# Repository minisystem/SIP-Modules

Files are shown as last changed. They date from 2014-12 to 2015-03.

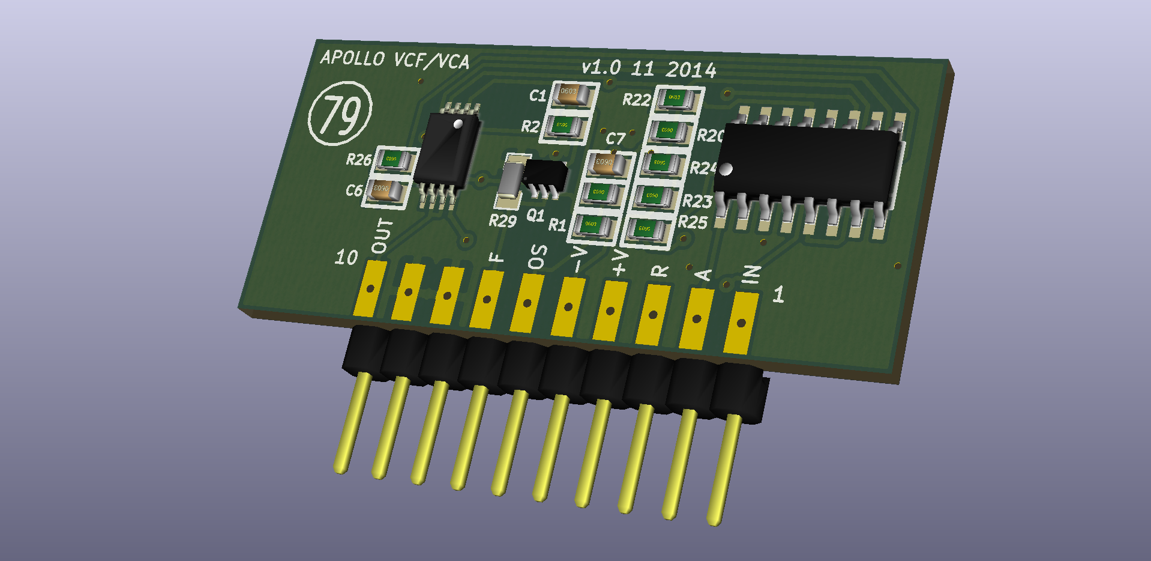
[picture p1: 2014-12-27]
VCF-VCA-SIP - Routing/VCF-VCA-SIP-back.png

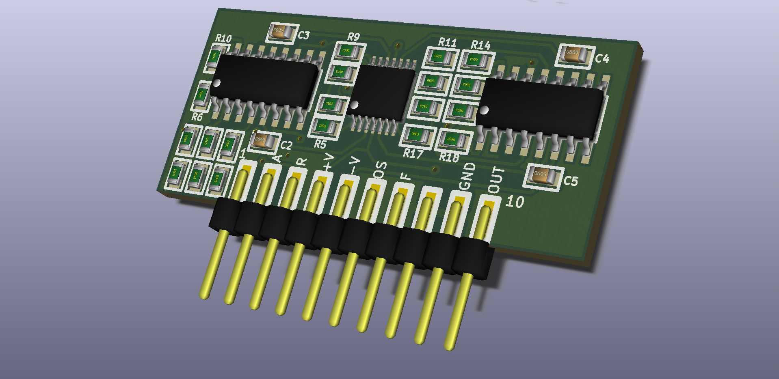
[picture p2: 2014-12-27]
VCF-VCA-SIP - Routing/VCF-VCA-SIP.png

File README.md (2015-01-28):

SIP-Modules
===========

Analogue SIP modules

Single Inline Pin [SIP] Package Modules for Analogue Synthesizer Design
===============================================================

******************************
IMPORTANT!- READ THIS FIRST!!!
*************************************************************************************************************
THESE REPOSITORIES ARE A MESS RIGHT NOW BECAUSE OF MY PREVIOUS AD HOC VERSION CONTROL
I will eventually tidy them up but at the moment I don't know which are the latest and fully correct versions 
*************************************************************************************************************

What are these?
===============

These are designs for modules that make up the bulidng blocks of an analogue synthesizer. They were inspired 
by the original Curtis Electromusic (CEM) chips used in dozens of 70s and 80s synthesizer designs. They are *NOT* 
electronically equivalent to the original CEM chips. They were designed to be compact modules for building 
a polyphonic analogue synthesizer. They use SMT parts but are designed for hand soldering. As there are parts on both sides of the board a substantial redesign might be required for automated assmebly by a pick-and-place assembly service.

VCO SIP
=======
This is an analogue Voltage Controlled Oscillator (VCO) module in a 30 mm x 18 mm 12 pin SIP package.
It is a classic SAW core design derived from the Terry Michaels/Mikulik/Electronotes/ASM-1 circuit. It employs 
waveshapers from George Hearn's HMVCO1c design, with modifications to limit output levels to 10V pp. Other
changes from the original Electronotes design include elimination of the linear FM input and swapping the CA3140 
integrator for the cheaper LF351. It uses an inexpensive BCM847 NPN matched transistor pair in contrast
to the super matched pairs (LS318, LM394, SSM2210, etc) called for in other SAW core designs.

VCF-VCA SIP
===========
This is a 4 pole LM13700 OTA-based Voltage Controlled Filter (VCF) in a 40 mm x 18 mm 10 pin SIP package.  It is derived from Roland filter designs based around the IR3109 quad OTA filter. Voltage controlled resonance is implemented with an LM13700 OTA cell and the spare OTA is used for a Voltage Controlled Amplifier (VCA), thus combining two functions into one module, similiar to the Roland D80017A VCF-VCA module used in the Juno 106.

EG ADSR SIP
===========
This is a voltage controlled Envelope Generator (EG) with Attack, Decay, Sustain and Release stages in a 30 mm x 18 mm 10 pin SIP package. It is derived from similar designs by Massimo Ischia and Scott Rider (OldCrow) with modifications to respond to 0-10V control voltages and to produce a 0-10V output.

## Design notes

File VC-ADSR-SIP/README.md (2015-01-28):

Voltage Controlled ADSR Envelope Generator
==========================================

This is a voltage controlled Envelope Generator (EG) with Attack, Decay, Sustain and Release stages in a 30 mm x 18 mm 12 pin SIP package. It is derived from similar designs by Massimo Ischia and Scott Rider (OldCrow) with modifications to respond to 0-10V control voltages and to produce a 0-10V output.

Massimo Ischia's version:
http://digilander.libero.it/ismsynth/vc-adsr-1.2.jpg

Scott Rider's version:
http://www.muffwiggler.com/forum/viewtopic.php?p=1151245
(scroll down for schematic in thread)

Notes
=====

Ideally, I'd like to eliminate the trimmers for Attack and Decay/Release times. I tried doing this in an early revision but needed to tweak the resistor values more than I expected so reverted to trimmers. However, in subsequent revisions I've hardly needed to make any adjustments at all. A 0603 or 0805 resistor should be able to bridge the T1 and T2 footprints.

Q1's schematic symbol has a pin numbering that swapped the emitter (pin 1) and base (pin 2) when used with the default SOT23 footprint. I fixed this by swapping the pad numbers on the SOT23 footprint module, but this change applies to *this project only*.

This project was created in Kicad 4022 but routed in 5112 using the CERN push and shove router. This means that the CvPcb footprint association uses the legacy library format and not the new library table format. I haven't tried to do the conversion yet.

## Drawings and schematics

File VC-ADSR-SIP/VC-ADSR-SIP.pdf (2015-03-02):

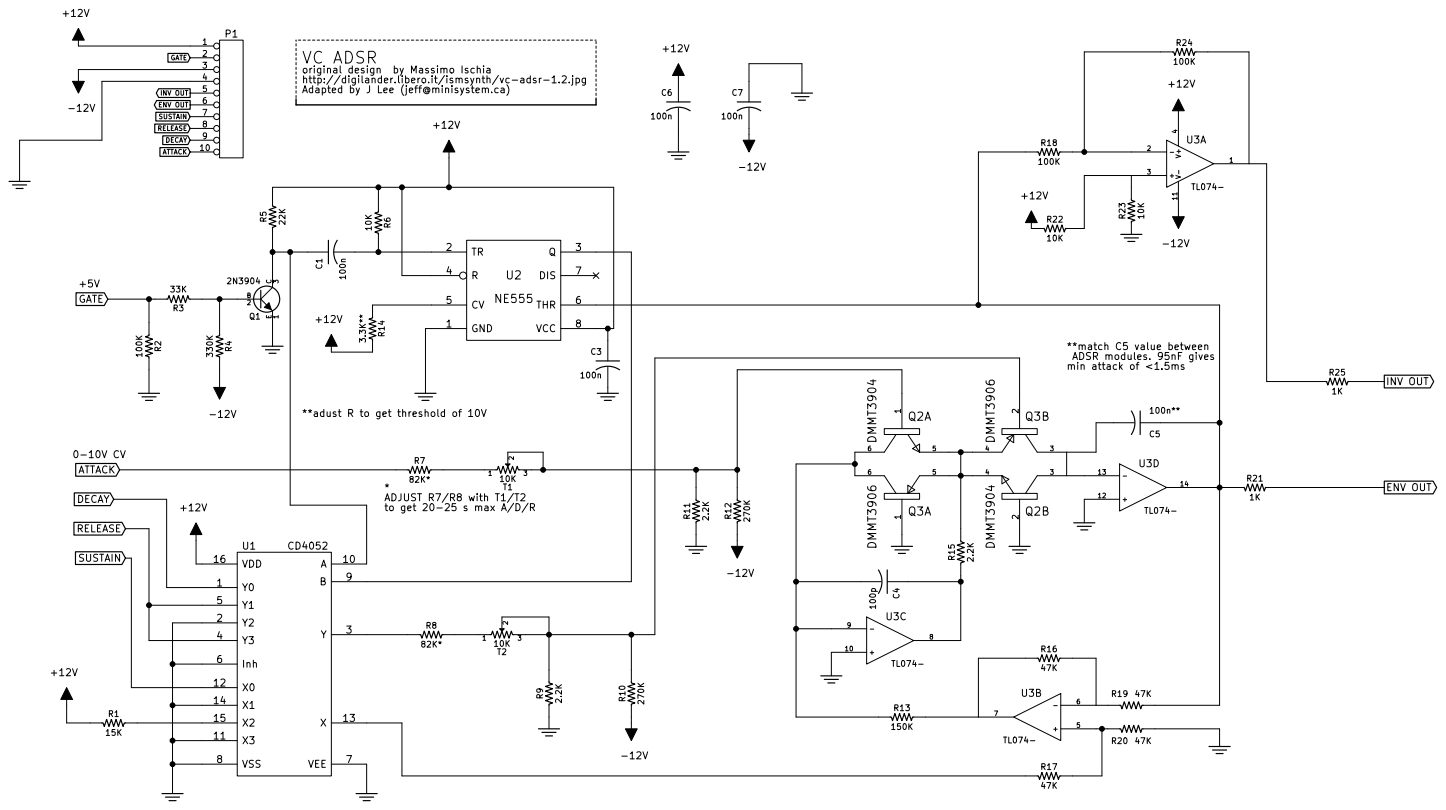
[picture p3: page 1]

original design by Massimo Ischia
http://digilander.libero.it/ismsynth/vc-adsr-1.2.jpg

ADSR modules. 95nF gives min attack of <1.5ms 0-10V CV

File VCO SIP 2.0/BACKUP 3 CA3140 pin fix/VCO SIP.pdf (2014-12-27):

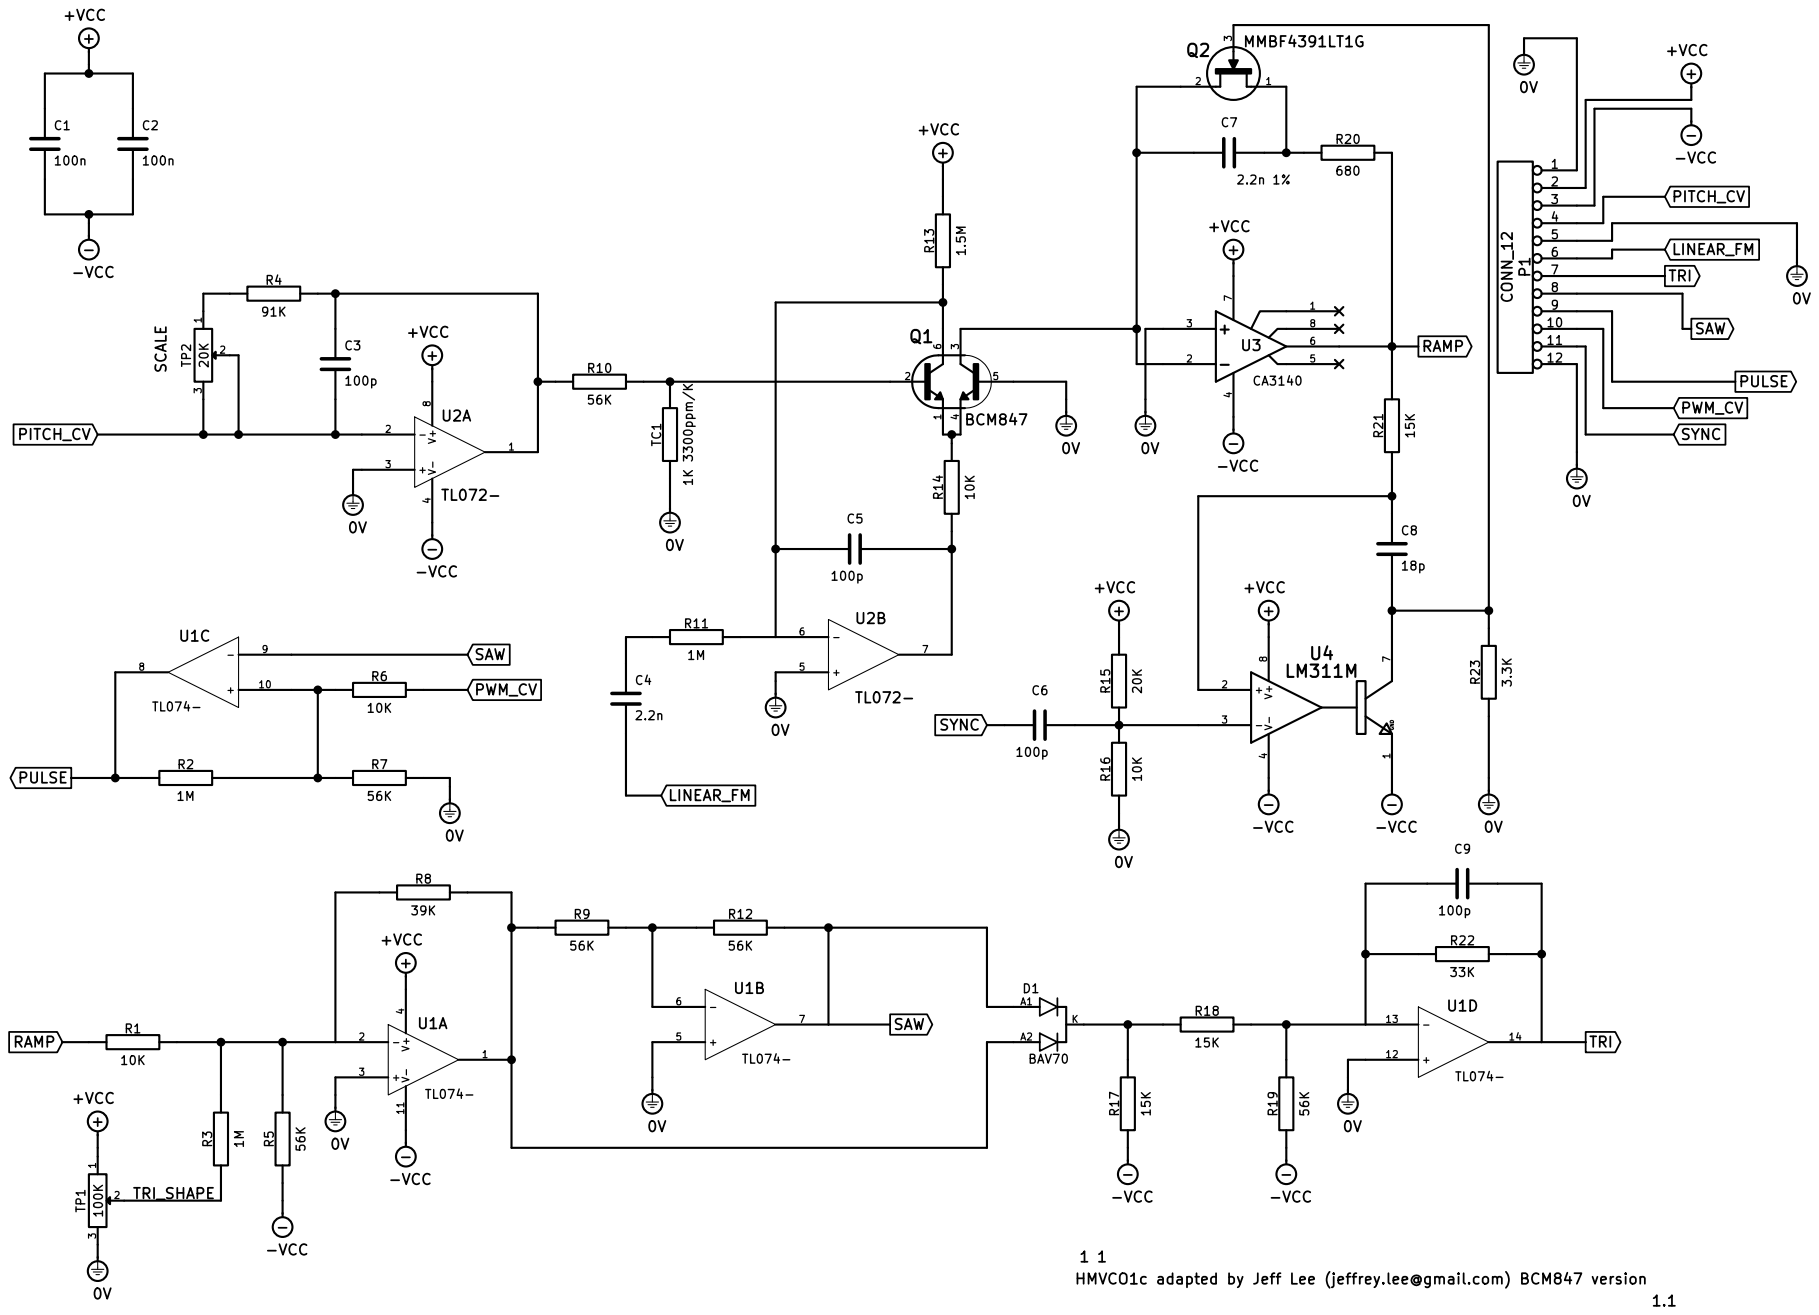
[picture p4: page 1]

1.1 HMVCO1c adapted by Jeff Lee (jeffrey.lee@gmail.com) BCM847 version

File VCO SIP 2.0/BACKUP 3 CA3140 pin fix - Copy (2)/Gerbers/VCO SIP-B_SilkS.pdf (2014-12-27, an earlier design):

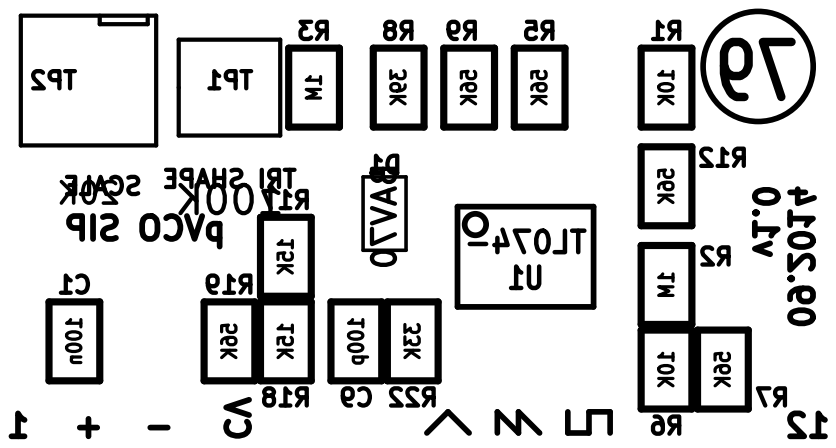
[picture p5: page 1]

SCALE TRI SHAPE 09.2014 pVCO SIP 79 BAV70 D1 TP2 20K

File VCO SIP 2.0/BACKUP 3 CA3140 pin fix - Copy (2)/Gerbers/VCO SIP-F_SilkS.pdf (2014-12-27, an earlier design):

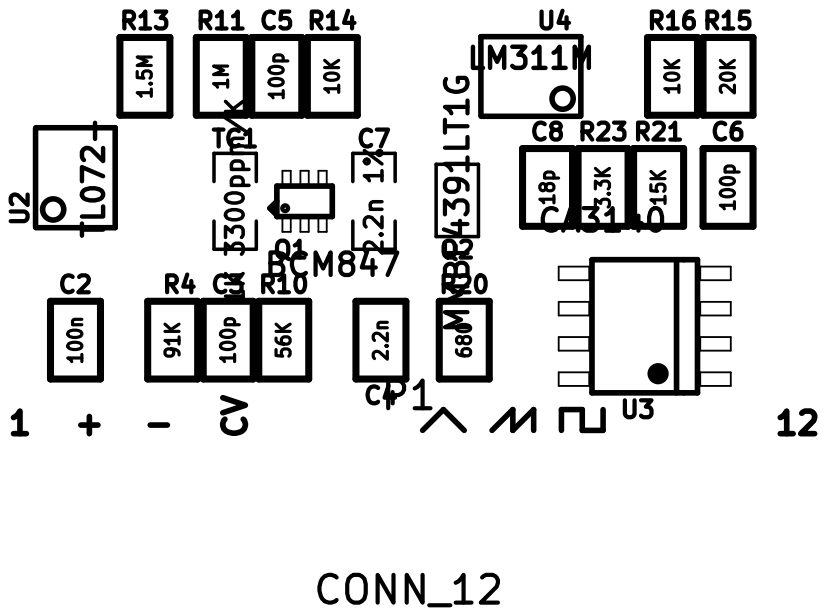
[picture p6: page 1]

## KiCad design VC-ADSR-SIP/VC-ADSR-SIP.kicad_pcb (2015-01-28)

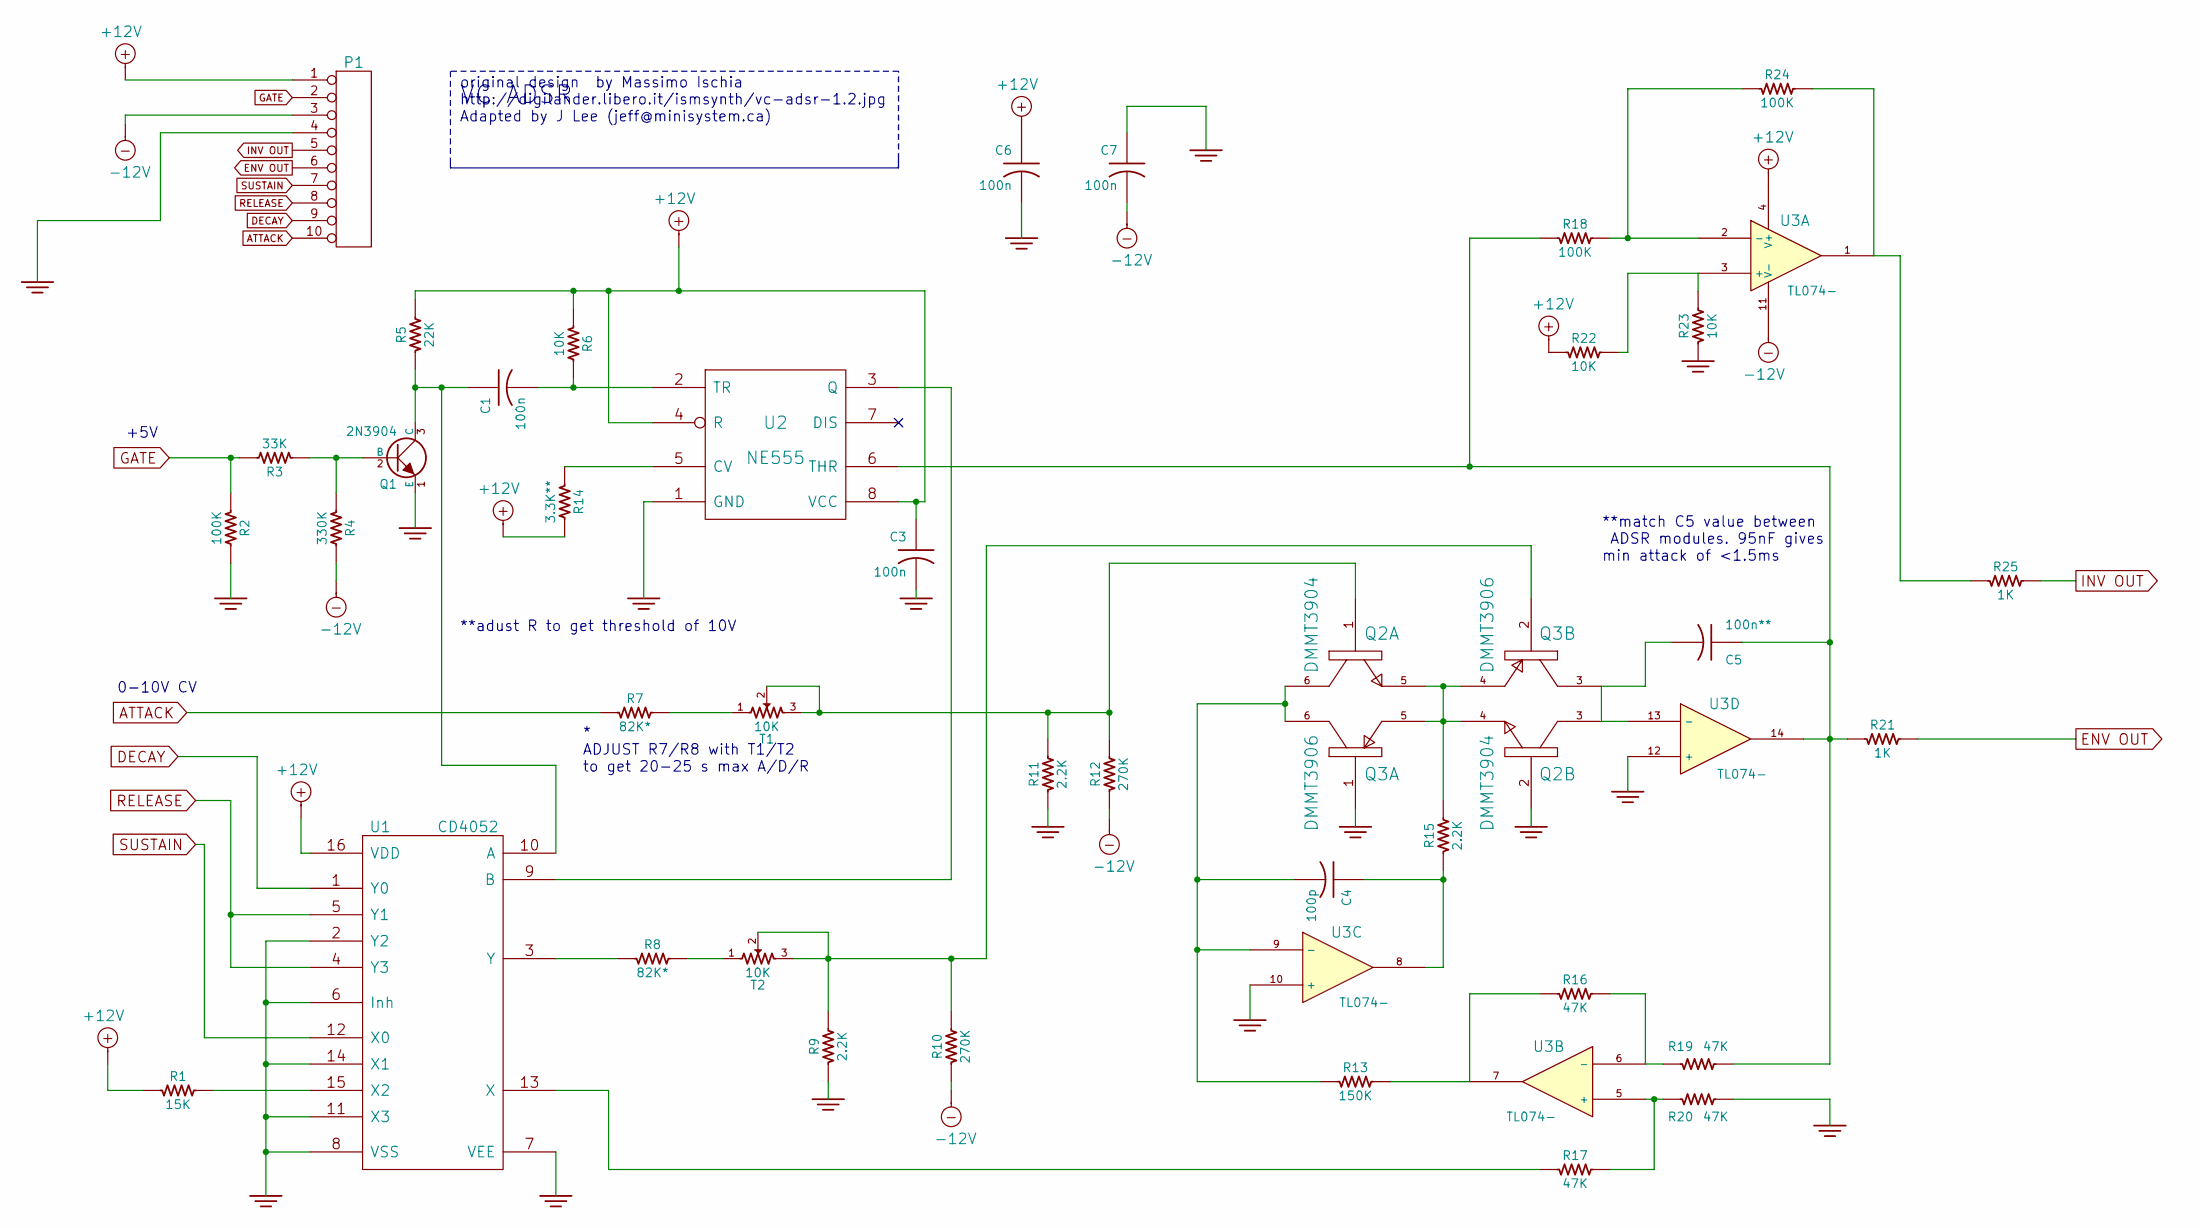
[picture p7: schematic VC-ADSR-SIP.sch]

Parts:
C1, C3, C6, C7: 100n
C4: 100p
C5: 100n**
P1: CONN_10
Q1: 2N3904
Q2: DMMT3904
Q3: DMMT3906
R1: 15K
R2, R18, R24: 100K
R3: 33K
R4: 330K
R5: 22K
R6, R22, R23: 10K
R7, R8: 82K*
R9, R11, R15: 2.2K
R10, R12: 270K
R13: 150K
R14: 3.3K**
R16, R17, R19, R20: 47K
R21, R25: 1K
T1, T2: 10K
U1: CD4052
U2: NE555
U3: TL074-

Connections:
+12V: C3.1, C6.1, P1.1, R1.1, R5.2, R6.1, R14.2, R22.1, U1.16 (VDD), U2.4 (R), U2.8 (VCC), U3.4 (V+)
-12V: C7.2, P1.3, R4.2, R10.1, R12.1, U3.11 (V-)
ATTACK: P1.10, R7.1
DECAY: P1.9, U1.1 (Y0)
ENV OUT: P1.6, R21.2
GATE: P1.2, R2.1, R3.2
GND: C3.2, C6.2, C7.1, P1.4, Q1.1 (E), Q2.2, Q3.1, R2.2, R9.1, R11.1, R20.2, R23.1, U1.2 (Y2), U1.6 (Inh), U1.7 (VEE), U1.8 (VSS), U1.11 (X3), U1.14 (X1), U2.1 (GND), U3.10 (+), U3.12 (+)
INV OUT: P1.5, R25.2
unnamed: Q1.2 (B), R3.1, R4.1
unnamed: C5.1, R18.1, R19.2, R21.1, U2.6 (THR), U3.14
unnamed: U1.9 (B), U2.3 (Q)
unnamed: C1.1, Q1.3 (C), R5.1, U1.10 (A)
unnamed: R14.1, U2.5 (CV)
unnamed: C1.2, R6.2, U2.2 (TR)
unnamed: R1.2, U1.15 (X2)
unnamed: R22.2, R23.2, U3.3 (+)
unnamed: R17.2, R20.1, U3.5 (+)
unnamed: C4.1, R15.1, U3.8
unnamed: R13.2, R16.1, U3.7
unnamed: R17.1, U1.13 (X)
unnamed: R16.2, R19.1, U3.6 (-)
unnamed: R18.2, R24.1, U3.2 (-)
unnamed: R8.2, T2.1
unnamed: R7.2, T1.1
unnamed: R24.2, R25.1, U3.1
unnamed: C5.2, Q2.3, Q3.3, U3.13 (-)
unnamed: Q2.4, Q2.5, Q3.4, Q3.5, R15.2
unnamed: R8.1, U1.3 (Y)
unnamed: Q3.2, R9.2, R10.2, T2.2, T2.3
unnamed: Q2.1, R11.2, R12.2, T1.2, T1.3
unnamed: C4.2, Q2.6, Q3.6, R13.1, U3.9 (-)
RELEASE: P1.8, U1.4 (Y3), U1.5 (Y1)
SUSTAIN: P1.7, U1.12 (X0)

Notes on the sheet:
**adust R to get threshold of 10V
* ADJUST R7/R8 with T1/T2 to get 20-25 s max A/D/R
**match C5 value between ADSR modules. 95nF gives min attack of <1.5ms
0-10V CV
+5V
VC ADSR
original design by Massimo Ischia http://digilander.libero.it/ismsynth/vc-adsr-1.2.jpg Adapted by J Lee (jeff@minisystem.ca)

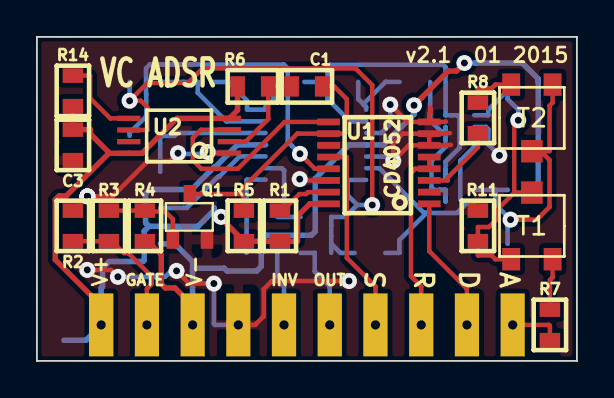
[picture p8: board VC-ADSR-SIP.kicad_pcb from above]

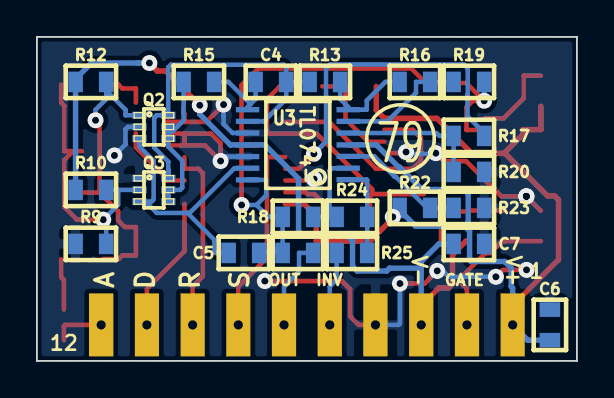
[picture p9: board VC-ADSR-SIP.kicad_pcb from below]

Board: 2 copper layers, 30.0 x 18.0 mm, 40 parts (22 on the bottom side), 33 nets.

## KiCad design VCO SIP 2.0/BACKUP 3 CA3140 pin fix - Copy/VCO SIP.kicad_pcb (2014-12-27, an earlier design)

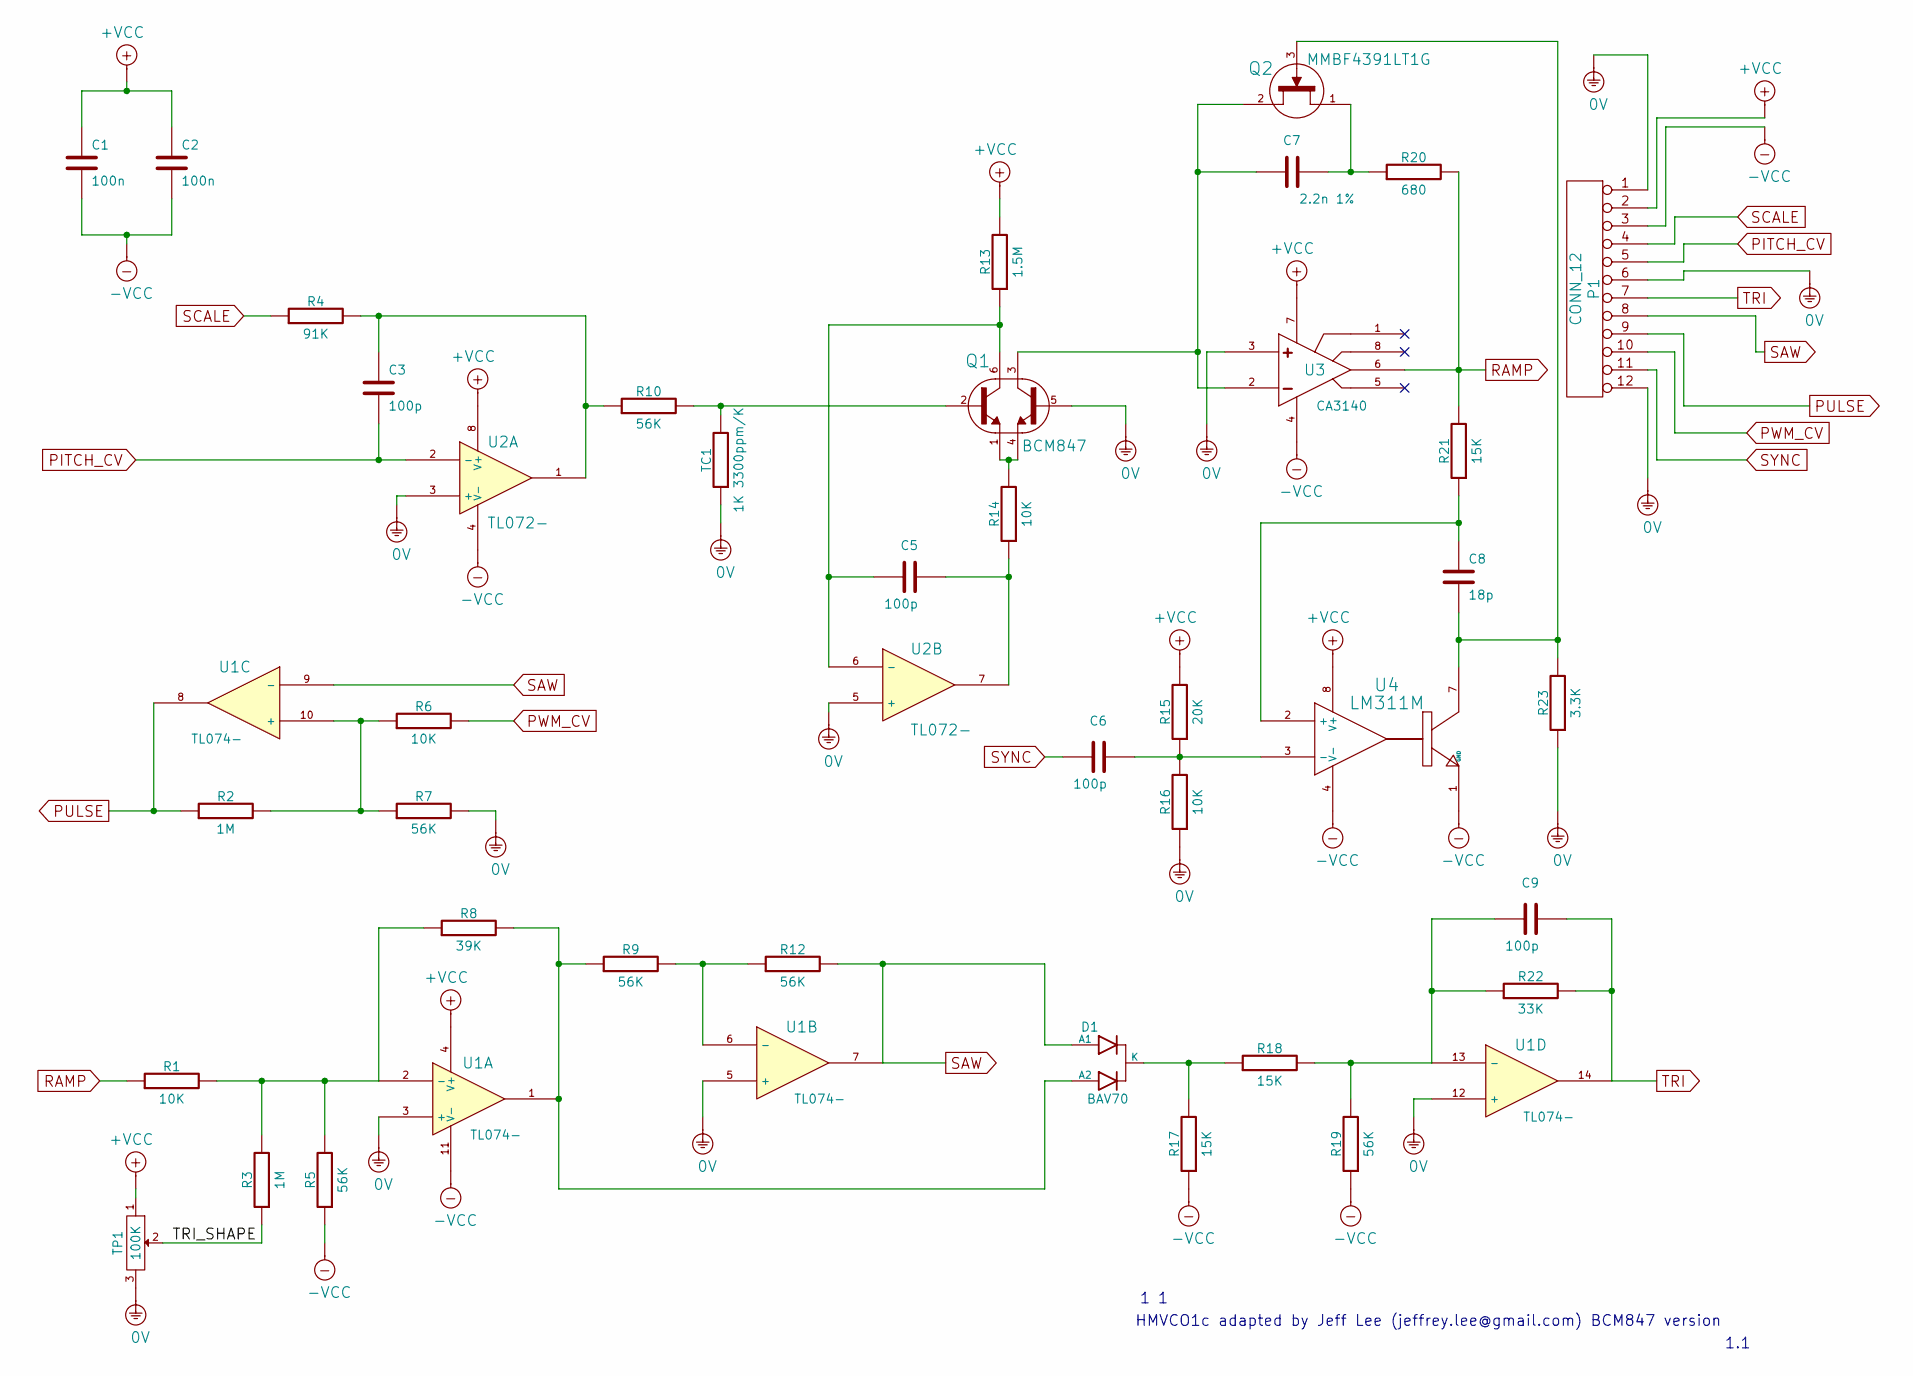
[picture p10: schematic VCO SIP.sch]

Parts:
C1, C2: 100n; Digikey 478-1395-1-ND
C3, C5, C6, C9: 100p; Digikey 399-1122-1-ND
C7: 2.2n 1%; Digikey 399-9198-1-ND
C8: 18p; Digikey 399-1112-1-ND
D1: BAV70; Digikey BAV70-V-GS08CT-ND
P1: CONN_12
Q1: BCM847; Digikey 568-6098-1-ND
Q2: MMBF4391LT1G; Digikey MMBF4391LT1GOSCT-ND
R1, R6, R14, R16: 10K; Digikey P10.0KCCT-ND
R2, R3: 1M; Digikey P1.00MCCT-ND
R4: 91K; Digikey P91.0KCCT-ND
R5, R7, R9, R10, R12, R19: 56K; Digikey P56.0KCCT-ND
R8: 39K; Digikey P39.0KCCT-ND
R13: 1.5M; Digikey P1.50MCCT-ND
R15: 20K; Digikey P20.0KCCT-ND
R17, R18, R21: 15K; Digikey P15.0KCCT-ND
R20: 680; Digikey P680CCT-ND
R22: 33K; Digikey P33.0KCCT-ND
R23: 3.3K; Digikey P3.30KCCT-ND
TC1: 1K 3300ppm/K; Digikey P1.0KCDCT-ND
TP1: 100K; Digikey SM-42TA104CT-ND
U1: TL074-
U2: TL072-
U3: CA3140; Digikey CA3140AMZ-ND
U4: LM311M; Digikey 296-1388-1-ND

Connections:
0V: P1.1, P1.6, P1.12, Q1.5 (B2), R7.2, R16.1, R23.1, TC1.1, TP1.3, U1.3 (+), U1.5 (+), U1.12 (+), U2.3 (+), U2.5 (+), U3.3 (NON)
+VCC: C1.1, C2.1, P1.2, R13.2, R15.2, TP1.1, U1.4 (V+), U2.8 (V+), U3.7 (V+), U4.8 (V+)
-VCC: C1.2, C2.2, P1.3, R5.1, R17.1, R19.1, U1.11 (V-), U2.4 (V-), U3.4 (V-), U4.1 (GND), U4.4 (V-)
/TRI_SHAPE: R3.1, TP1.2
unnamed: C3.1, R4.2, R10.1, U2.1
unnamed: C5.1, Q1.6 (C1), R13.1, U2.6 (-)
unnamed: C5.2, R14.1, U2.7
unnamed: C6.2, R15.1, R16.2, U4.3 (-)
unnamed: C7.1, Q1.3 (C2), Q2.2 (S), U3.2 (INVERTING)
unnamed: C7.2, Q2.1 (D), R20.1
unnamed: C8.1, R21.1, U4.2 (+)
unnamed: C8.2, Q2.3 (G), R23.2, U4.7
unnamed: C9.1, R18.2, R19.2, R22.1, U1.13 (-)
unnamed: D1.2 (A2), R8.2, R9.1, U1.1
unnamed: D1.3 (K), R17.2, R18.1
unnamed: Q1.1 (E1), Q1.4 (E2), R14.2
unnamed: Q1.2 (B1), R10.2, TC1.2
unnamed: R1.2, R3.2, R5.2, R8.1, U1.2 (-)
unnamed: R2.2, R6.1, R7.1, U1.10 (+)
unnamed: R9.2, R12.1, U1.6 (-)
PITCH_CV: C3.2, P1.5, U2.2 (-)
PULSE: P1.9, R2.1, U1.8
PWM_CV: P1.10, R6.2
RAMP: R1.1, R20.2, R21.2, U3.6 (OUTPUT)
SAW: D1.1 (A1), P1.8, R12.2, U1.7, U1.9 (-)
SCALE: P1.4, R4.1
SYNC: C6.1, P1.11
TRI: C9.2, P1.7, R22.2, U1.14

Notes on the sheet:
1.1
HMVCO1c adapted by Jeff Lee (jeffrey.lee@gmail.com) BCM847 version

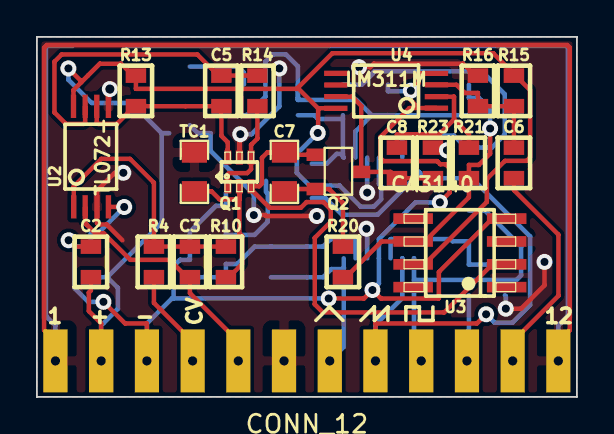
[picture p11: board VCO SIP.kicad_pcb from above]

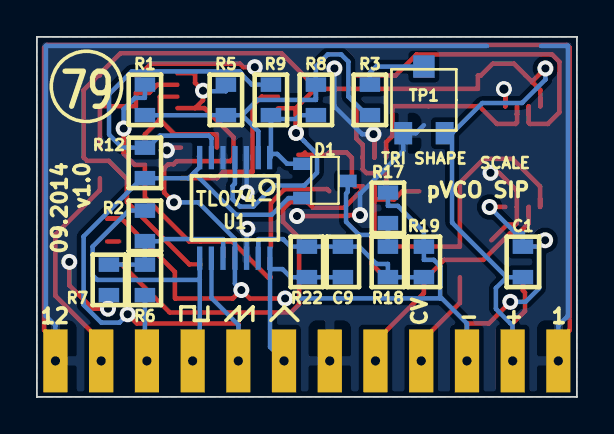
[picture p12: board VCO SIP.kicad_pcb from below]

Board: 2 copper layers, 30.0 x 20.0 mm, 40 parts (18 on the bottom side), 28 nets.

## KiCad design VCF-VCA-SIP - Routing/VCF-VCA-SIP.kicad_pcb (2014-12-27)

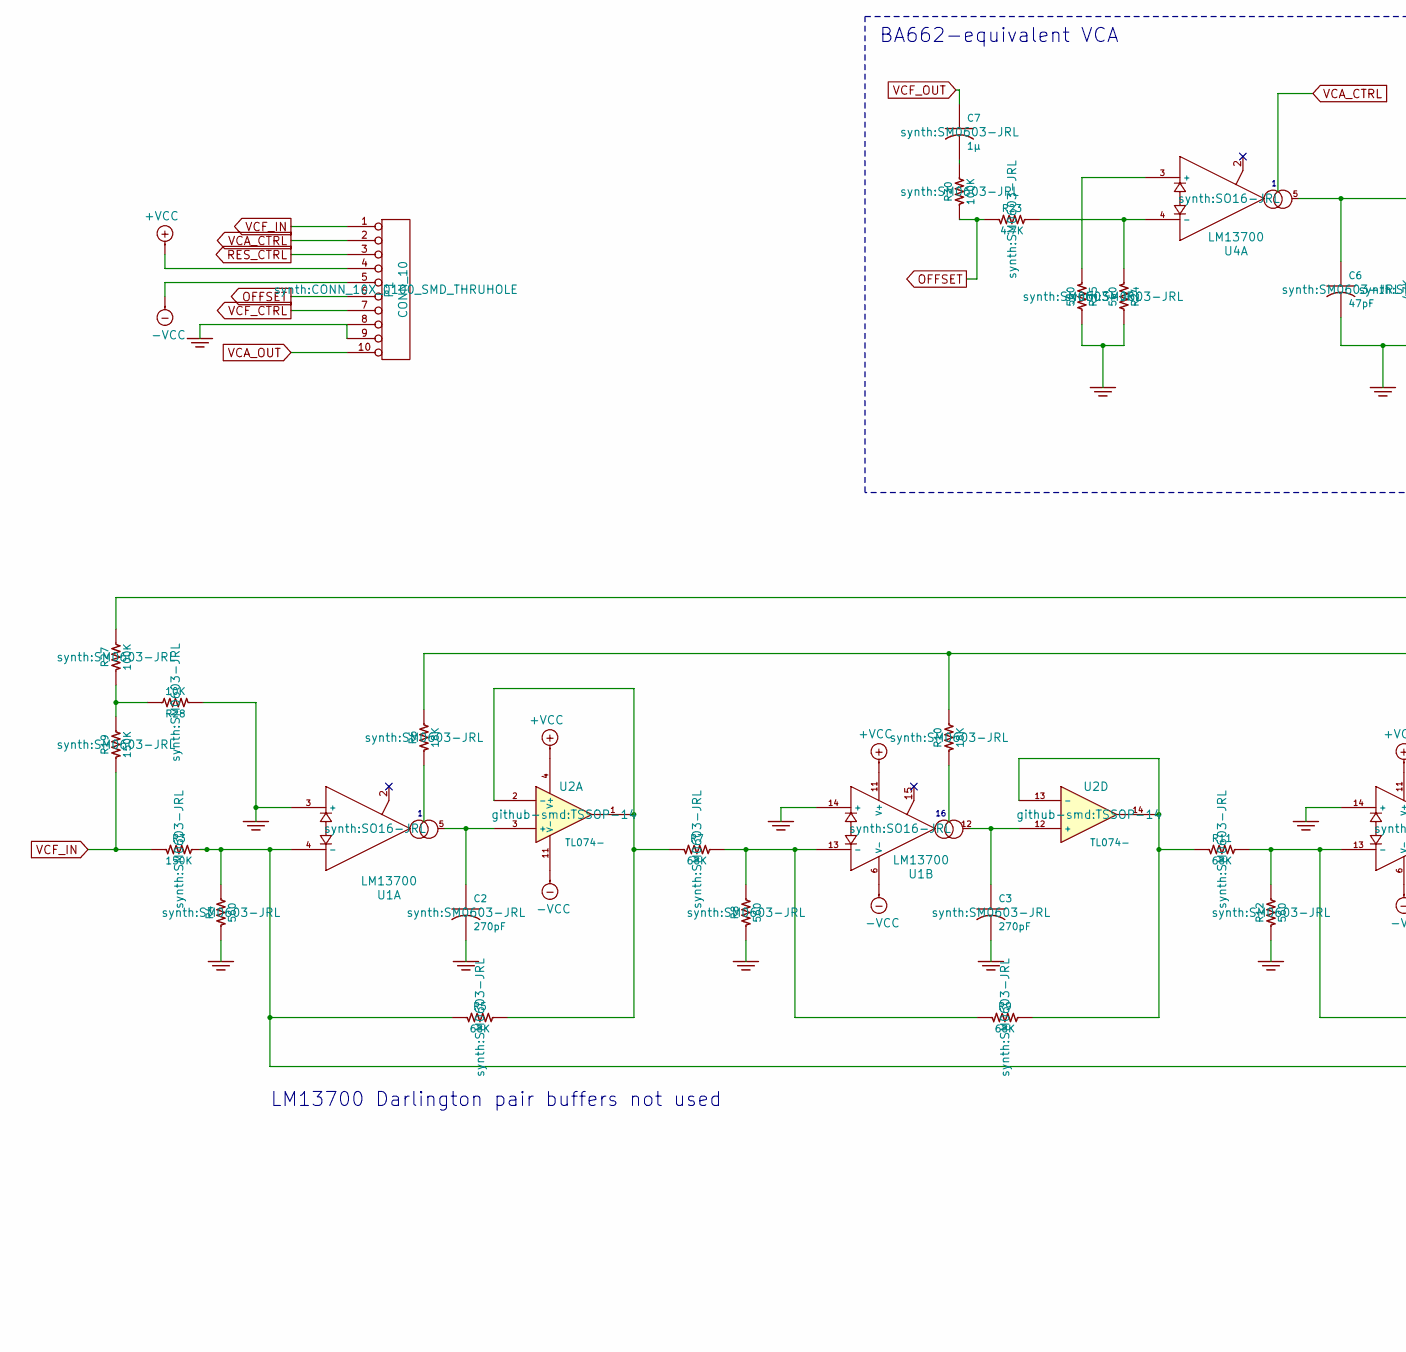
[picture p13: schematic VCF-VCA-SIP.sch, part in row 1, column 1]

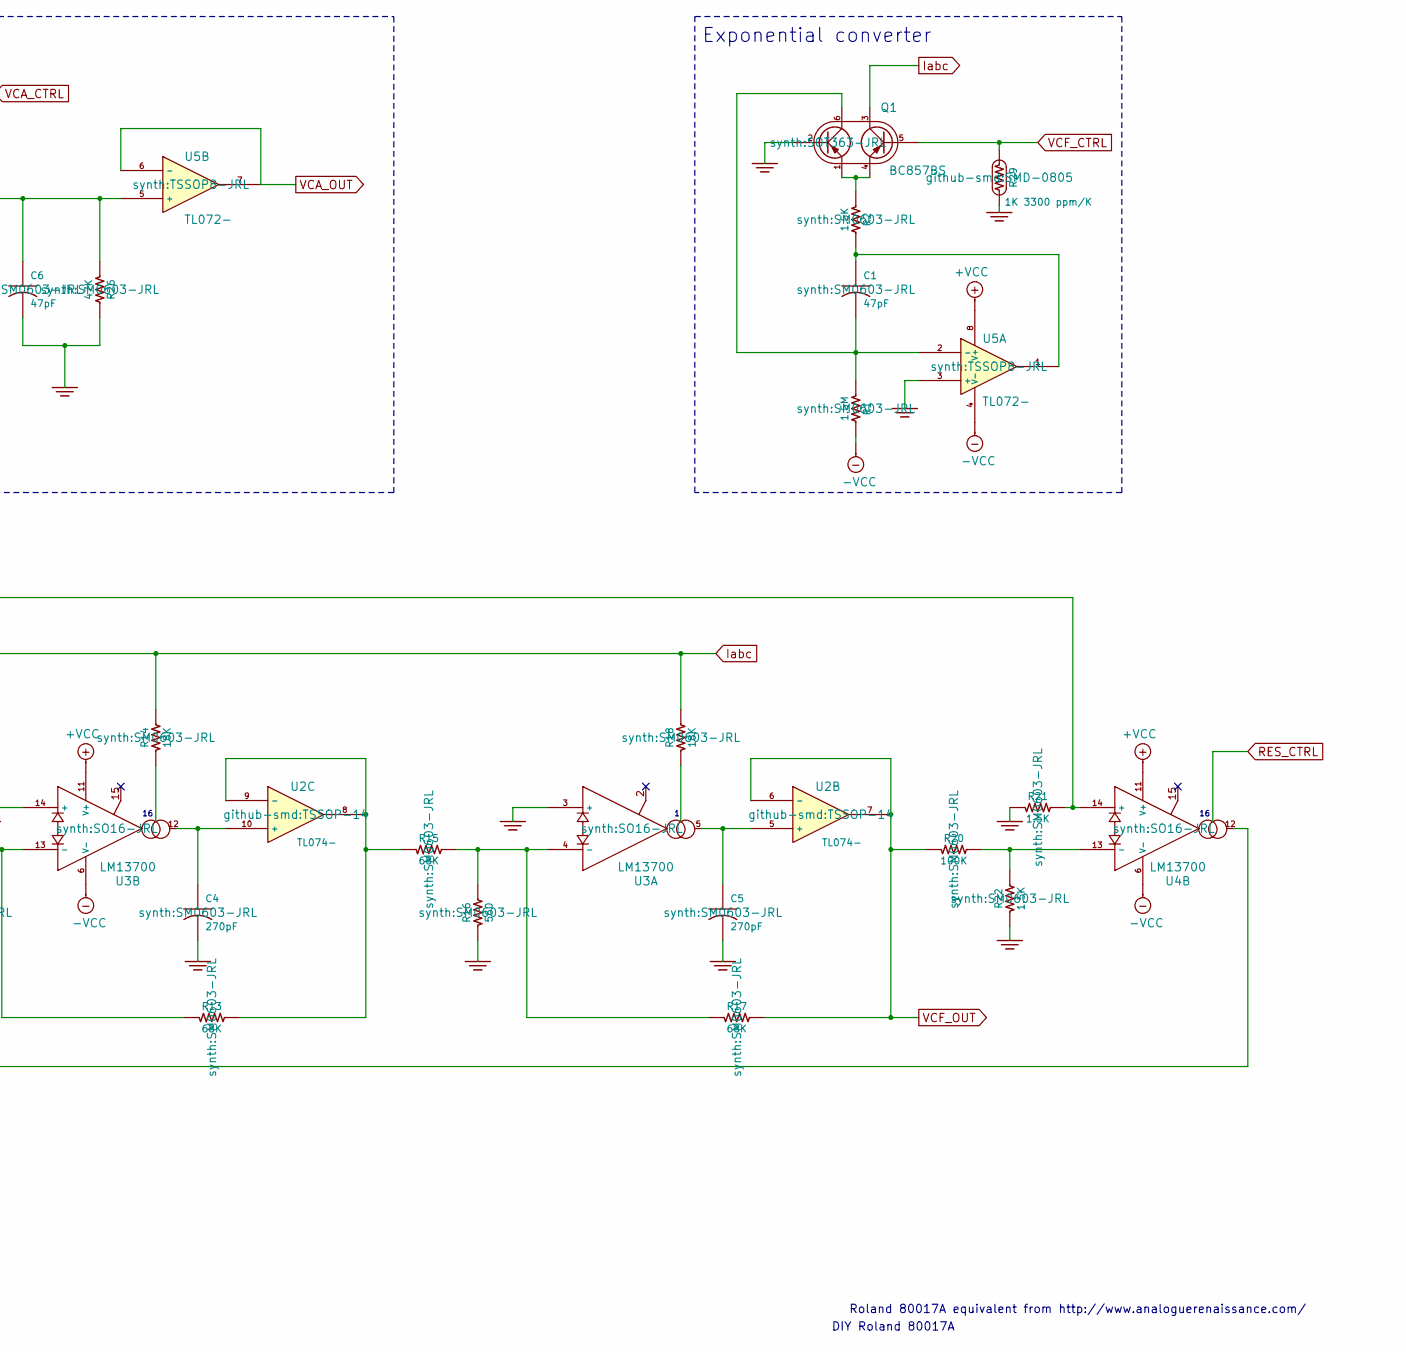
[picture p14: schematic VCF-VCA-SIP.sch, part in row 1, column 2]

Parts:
C1, C6: 47pF; SM0603-JRL
C2, C3, C4, C5: 270pF; SM0603-JRL
C7: 1μ; SM0603-JRL
P1: CONN_10; CONN_10X_0100_SMD_THRUHOLE
Q1: BC857BS; SOT363-JRL
R1: 1.5M; SM0603-JRL
R2, R21, R22: 1.5K; SM0603-JRL
R3, R19: 150K; SM0603-JRL
R4, R8, R12, R16, R24, R25: 560; SM0603-JRL
R5, R7, R9, R11, R13, R15, R17: 68K; SM0603-JRL
R6, R10, R14, R18: 18K; SM0603-JRL
R20, R27, R30: 100K; SM0603-JRL
R23: 4.7K; SM0603-JRL
R26: 47K; SM0603-JRL
R28: 10K; SM0603-JRL
R29: 1K 3300 ppm/K; SMD-0805
U1, U3, U4: LM13700; SO16-JRL
U2: TL074-; TSSOP-14
U5: TL072-; TSSOP8-JRL

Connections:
+VCC: P1.4, U1.11 (V+), U2.4 (V+), U3.11 (V+), U4.11 (V+), U5.8 (V+)
-VCC: P1.5, R1.2, U1.6 (V-), U2.11 (V-), U3.6 (V-), U4.6 (V-), U5.4 (V-)
GND: C2.2, C3.2, C4.2, C5.2, C6.2, P1.8, P1.9, Q1.2 (B1), R4.1, R8.1, R12.1, R16.1, R21.2, R22.1, R24.2, R25.2, R26.2, R28.1, R29.2, U1.3 (+), U1.14 (+), U3.3 (+), U3.14 (+), U5.3 (+)
Iabc: Q1.3 (C2), R6.2, R10.2, R14.2, R18.2
unnamed: C1.1, R2.2, U5.1
unnamed: C1.2, Q1.6 (C1), R1.1, U5.2 (-)
unnamed: C2.1, U1.5, U2.3 (+)
unnamed: C3.1, U1.12, U2.12 (+)
unnamed: C4.1, U2.10 (+), U3.12
unnamed: C5.1, U2.5 (+), U3.5
unnamed: C6.1, R26.1, U4.5, U5.5 (+)
unnamed: C7.2, R30.2
unnamed: Q1.1 (E1), Q1.4 (E2), R2.1
unnamed: R3.2, R4.2, R5.2, U1.4 (-), U4.12
unnamed: R5.1, R7.2, U2.1, U2.2 (-)
unnamed: R6.1, U1.1
unnamed: R7.1, R8.2, R9.2, U1.13 (-)
unnamed: R10.1, U1.16
unnamed: R11.1, R12.2, R13.2, U3.13 (-)
unnamed: R9.1, R11.2, U2.13 (-), U2.14
unnamed: R13.1, R15.2, U2.8, U2.9 (-)
unnamed: R14.1, U3.16
unnamed: R15.1, R16.2, R17.2, U3.4 (-)
unnamed: R18.1, U3.1
unnamed: R19.2, R27.1, R28.2
unnamed: R20.1, R22.2, U4.13 (-)
unnamed: R21.1, R27.2, U4.14 (+)
unnamed: R23.1, R24.1, U4.4 (-)
unnamed: R25.1, U4.3 (+)
OFFSET: P1.6, R23.2, R30.1
RES_CTRL: P1.3, U4.16
VCA_CTRL: P1.2, U4.1
VCA_OUT: P1.10, U5.6 (-), U5.7
VCF_CTRL: P1.7, Q1.5 (B2), R29.1
VCF_IN: P1.1, R3.1, R19.1
VCF_OUT: C7.1, R17.1, R20.2, U2.6 (-), U2.7

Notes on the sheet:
LM13700 Darlington pair buffers not used
BA662-equivalent VCA
Exponential converter
DIY Roland 80017A
Roland 80017A equivalent from http://www.analoguerenaissance.com/

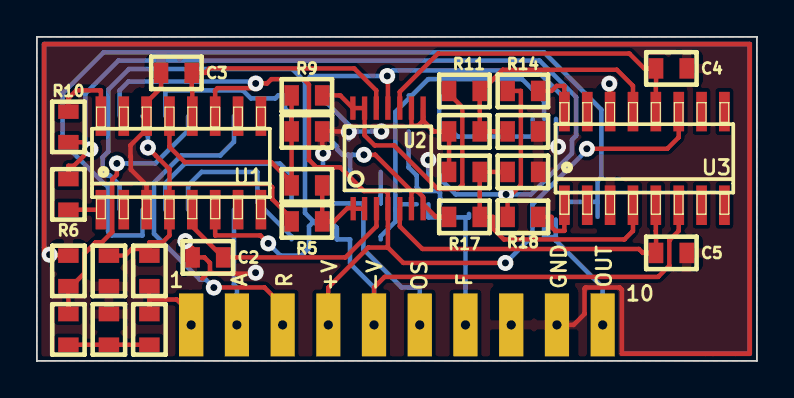
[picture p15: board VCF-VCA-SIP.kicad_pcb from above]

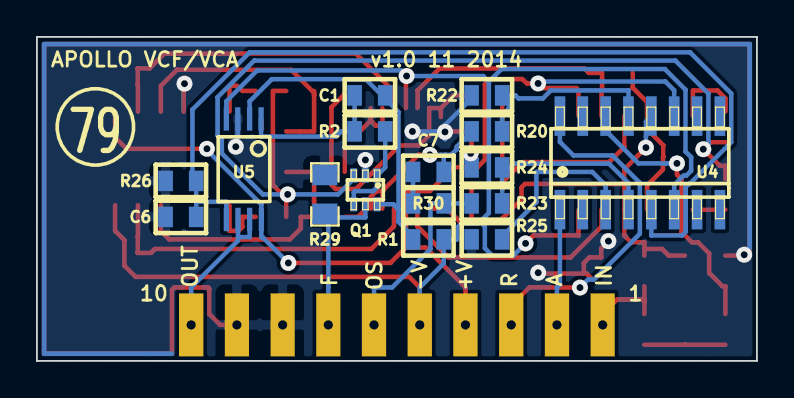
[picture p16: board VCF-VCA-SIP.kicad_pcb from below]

Board: 2 copper layers, 40.0 x 18.0 mm, 44 parts (16 on the bottom side), 36 nets.

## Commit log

2014-12-27 First add
    [VC ADSR ADR trim - Copy - Copy.kicad_pcb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]
2015-01-28 changed Q1 footprint E and B were swapped
    [VC ADSR ADR trim - Copy.kicad_pcb]
2015-01-28 gerbers with fixed Q1 footprint plotted
    [VC ADSR ADR trim - Copy-B_Cu.gbl, VC ADSR ADR trim - Copy-B_Mask.gbs, VC ADSR ADR trim - Copy-B_SilkS.gbo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]
2015-01-28 changed VC ADSR folder to name without spaces
    [VC ADSR ADR trim - Copy - Copy.kicad_pcb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]
2015-01-28 cleaned up VC ADSR directory
    [VC ADSR ADR trim - Copy - Copy.kicad_pcb, VC ADSR ADR trim routing 2.dsn, VC ADSR ADR trim routing 2.kicad_pcb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]
2015-03-02 updated schematic PDF
